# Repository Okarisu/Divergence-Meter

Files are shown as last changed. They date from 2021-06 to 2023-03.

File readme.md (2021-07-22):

# Divergence meter

## from Steins;Gate series and visual novels

## Note - this `readme` is in process of writing, the same as the code

## Basic synopsis

In this project I am trying to build working prototype of Divergence meter that appeared in Steins;Gate anime series and Visual novels.

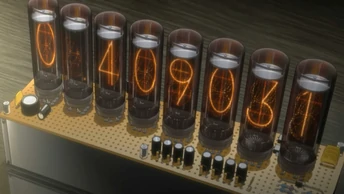
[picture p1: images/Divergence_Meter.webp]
Divergence meter


I use arduino board in combination with shift registers SN74HC595N to drive itrons IV-6.

## byte values for shift registers

### Grids

| Itron No. | byte value |
| --- | --- |
| first |  B01111111 |
| second | B10111111 |
| third | B11011111 |
| fourth | B11101111 |
| fifth | B11110111 |
| sixth | B11111011 |
| seventh | B11111101 |
| eighth | B11111110 |

### Numbers & symbols

| Number | byte value |
| --- | --- |
| zero | B00000011 |
| one | B10011111 |
| two | B00100101 |
| three | B00001101 |
| four | B10110001 |
| five | B01001001 |
| six | B01000001 |
| seven | B00011111 |
| eight | B00000001 |
| nine | B00001001 |

| symbol | byte value |
| --- | --- |
| dot | B11111110 |
| stroke | B11111101 |

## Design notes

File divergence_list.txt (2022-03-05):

-.275349ω
-.195284ω

0.295582α
0.328403α
0.334581α
0.337161α
0.337187α
0.337199α
0.337337α
0.409420α
0.409431α
0.456903α
0.456914α 
0.456923α
0.509736a
0.523299α
0.523307α
0.549111α
0.571015α
0.571024α
0.571046α

SG0
0.571???α
0.571082α

SG
1.048596 (the Steins Gate)
1.048599
1.048728
1.049326X

1.053649β
1.055821β
1.064750β
1.097302β
1.097302β
1.123581β
1.129848β
1.129954β
1.130205β
1.130206β, 1.130207β, 1.130208β, 1.130209β, 1.130211β, 1.130212β
1.130238β
1.130426β
1.143688β
1.382733β

2.615074γ

3.019430δ 
3.030493δ
3.130238δ
3.182879δ
3.372329δ
3.386019δ
3.406288δ
3.600104δ
3.667293δ
3.372329δ, 3.386019δ, 3.406288δ, 3.600104δ, 3.667293δ

4.456441ε, 4.456442ε, 4.493623ε, 4.493624ε, 4.530805ε, 4.530806ε

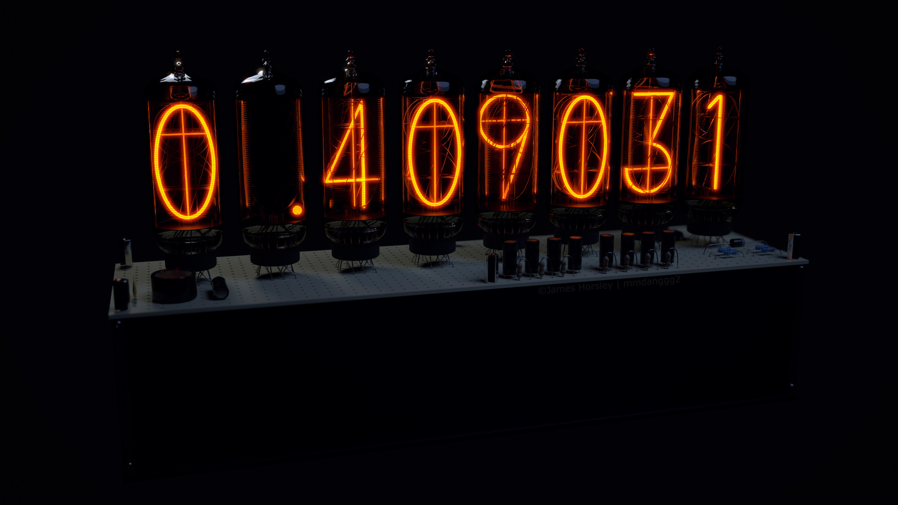
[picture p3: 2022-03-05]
images/james-horsley-nixieview3wm.jpg

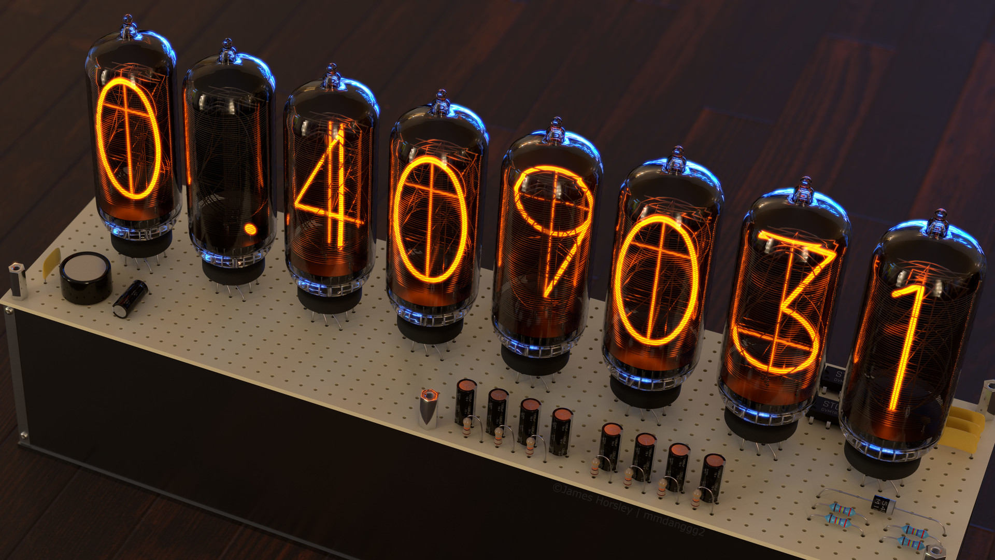
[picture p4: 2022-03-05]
images/james-horsley-nixie8kwm.jpg

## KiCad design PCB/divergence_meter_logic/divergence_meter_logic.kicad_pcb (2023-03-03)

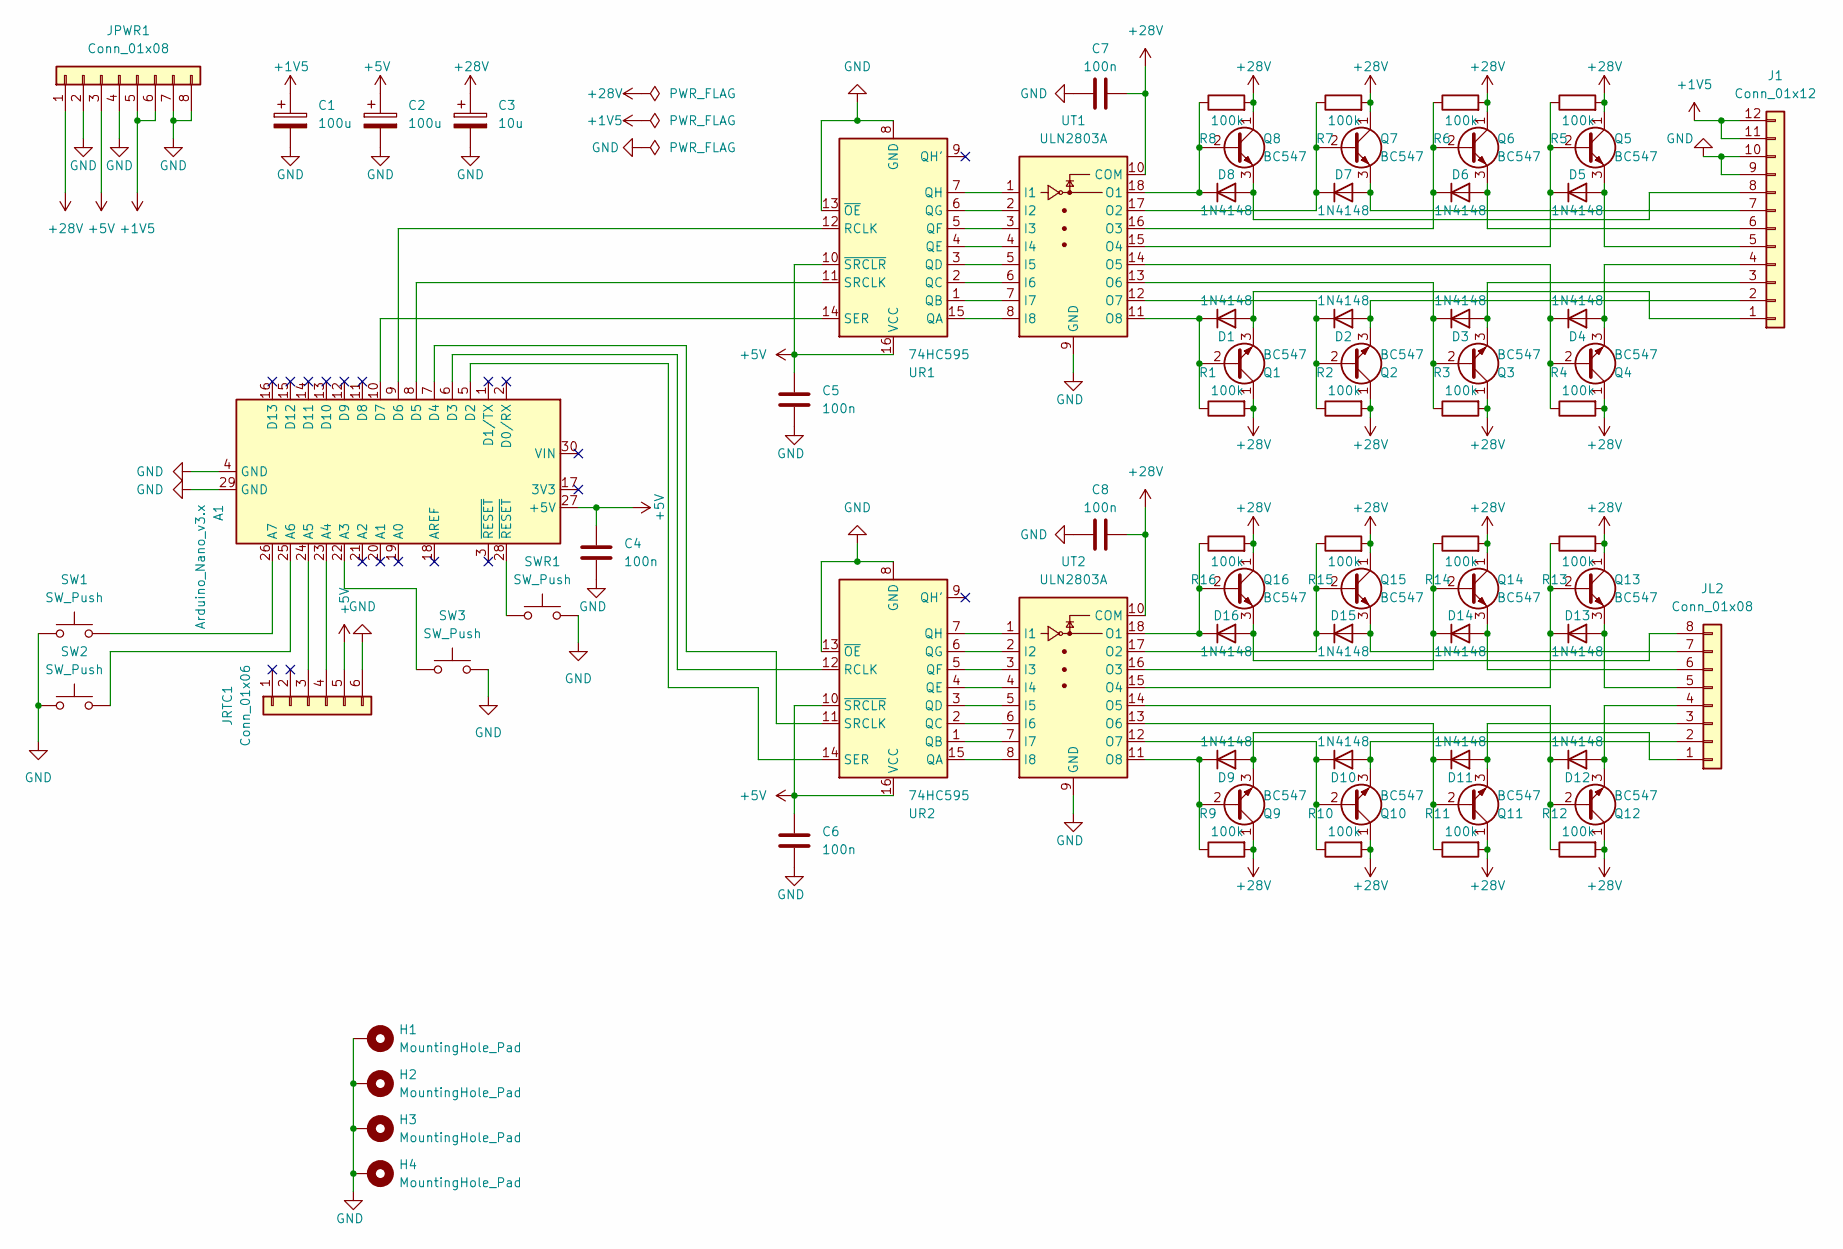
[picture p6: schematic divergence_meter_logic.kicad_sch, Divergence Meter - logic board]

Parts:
A1: Arduino_Nano_v3.x; Arduino_Nano
C1, C2: 100u; CP_Radial_D5.0mm_P2.00mm
C3: 10u; CP_Radial_D5.0mm_P2.00mm
C4, C5, C6, C7, C8: 100n; C_Disc_D5.0mm_W2.5mm_P5.00mm
D1, D2, D3, D4, D5, D6, D7, D8, D9, D10, D11, D12, D13, D14, D15, D16: 1N4148; D_DO-35_SOD27_P2.54mm_Vertical_KathodeUp
H1, H2, H3, H4: MountingHole_Pad; MountingHole_3.5mm_Pad_Via
J1: Conn_01x12; PinSocket_1x12_P2.54mm_Vertical
JL2: Conn_01x08; PinSocket_1x08_P2.54mm_Vertical
JPWR1: Conn_01x08; PinHeader_1x08_P2.54mm_Horizontal
JRTC1: Conn_01x06; PinSocket_1x06_P2.54mm_Horizontal
Q1, Q2, Q3, Q4, Q5, Q6, Q7, Q8, Q9, Q10, Q11, Q12, Q13, Q14, Q15, Q16: BC547; TO-92_Inline
R1, R2, R3, R4, R5, R6, R7, R8, R9, R10, R11, R12, R13, R14, R15, R16: 100k; R_Axial_DIN0204_L3.6mm_D1.6mm_P2.54mm_Vertical
SW1, SW2, SW3: SW_Push; SW_PUSH_6mm_H4.3mm
SWR1: SW_Push; SW_PUSH_6mm_H4.3mm
UR1, UR2: 74HC595; DIP-16_W7.62mm_Socket
UT1, UT2: ULN2803A; DIP-18_W7.62mm_Socket

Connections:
+1V5: C1.1, J1.11, J1.12, JPWR1.5, JPWR1.6
+5V: A1.27 (+5V), C2.1, C4.1, C5.1, C6.1, JPWR1.3, JRTC1.5, UR1.10 (~SRCLR), UR1.16 (VCC), UR2.10 (~SRCLR), UR2.16 (VCC)
+28V: C3.1, C7.2, C8.2, JPWR1.1, Q1.1 (C), Q2.1 (C), Q3.1 (C), Q4.1 (C), Q5.1 (C), Q6.1 (C), Q7.1 (C), Q8.1 (C), Q9.1 (C), Q10.1 (C), Q11.1 (C), Q12.1 (C), Q13.1 (C), Q14.1 (C), Q15.1 (C), Q16.1 (C), R1.2, R2.2, R3.2, R4.2, R5.2, R6.2, R7.2, R8.2, R9.2, R10.2, R11.2, R12.2, R13.2, R14.2, R15.2, R16.2, UT1.10 (COM), UT2.10 (COM)
GND: A1.4 (GND), A1.29 (GND), C1.2, C2.2, C3.2, C4.2, C5.2, C6.2, C7.1, C8.1, H1.1, H2.1, H3.1, H4.1, J1.9, J1.10, JPWR1.2, JPWR1.4, JPWR1.7, JPWR1.8, JRTC1.6, SW1.1, SW2.1, SW3.2, SWR1.2, UR1.8 (GND), UR1.13 (~OE), UR2.8 (GND), UR2.13 (~OE), UT1.9 (GND), UT2.9 (GND)
unnamed: A1.5 (D2), UR2.14 (SER)
unnamed: A1.6 (D3), UR2.12 (RCLK)
unnamed: A1.7 (D4), UR2.11 (SRCLK)
unnamed: A1.22 (A3), SW3.1
unnamed: A1.23 (A4), JRTC1.4
unnamed: A1.24 (A5), JRTC1.3
unnamed: A1.25 (A6), SW2.2
unnamed: A1.26 (A7), SW1.2
unnamed: A1.28 (~RESET), SWR1.1
unnamed: D1.1 (K), Q1.2 (B), R1.1, UT1.11 (O8)
unnamed: D1.2 (A), J1.1, Q1.3 (E)
unnamed: D2.1 (K), Q2.2 (B), R2.1, UT1.12 (O7)
unnamed: D2.2 (A), J1.2, Q2.3 (E)
unnamed: D3.1 (K), Q3.2 (B), R3.1, UT1.13 (O6)
unnamed: D3.2 (A), J1.3, Q3.3 (E)
unnamed: D4.1 (K), Q4.2 (B), R4.1, UT1.14 (O5)
unnamed: D4.2 (A), J1.4, Q4.3 (E)
unnamed: D5.1 (K), Q5.2 (B), R5.1, UT1.15 (O4)
unnamed: D5.2 (A), J1.5, Q5.3 (E)
unnamed: D6.1 (K), Q6.2 (B), R6.1, UT1.16 (O3)
unnamed: D6.2 (A), J1.6, Q6.3 (E)
unnamed: D7.1 (K), Q7.2 (B), R7.1, UT1.17 (O2)
unnamed: D7.2 (A), J1.7, Q7.3 (E)
unnamed: D8.1 (K), Q8.2 (B), R8.1, UT1.18 (O1)
unnamed: D8.2 (A), J1.8, Q8.3 (E)
unnamed: D9.1 (K), Q9.2 (B), R9.1, UT2.11 (O8)
unnamed: D9.2 (A), JL2.1, Q9.3 (E)
unnamed: D10.1 (K), Q10.2 (B), R10.1, UT2.12 (O7)
unnamed: D10.2 (A), JL2.2, Q10.3 (E)
unnamed: D11.1 (K), Q11.2 (B), R11.1, UT2.13 (O6)
unnamed: D11.2 (A), JL2.3, Q11.3 (E)
unnamed: D12.1 (K), Q12.2 (B), R12.1, UT2.14 (O5)
unnamed: D12.2 (A), JL2.4, Q12.3 (E)
unnamed: D13.1 (K), Q13.2 (B), R13.1, UT2.15 (O4)
unnamed: D13.2 (A), JL2.5, Q13.3 (E)
unnamed: D14.1 (K), Q14.2 (B), R14.1, UT2.16 (O3)
unnamed: D14.2 (A), JL2.6, Q14.3 (E)
unnamed: D15.1 (K), Q15.2 (B), R15.1, UT2.17 (O2)
unnamed: D15.2 (A), JL2.7, Q15.3 (E)
unnamed: D16.1 (K), Q16.2 (B), R16.1, UT2.18 (O1)
unnamed: D16.2 (A), JL2.8, Q16.3 (E)
unnamed: UR1.1 (QB), UT1.7 (I7)
unnamed: UR1.2 (QC), UT1.6 (I6)
unnamed: UR1.3 (QD), UT1.5 (I5)
unnamed: UR1.4 (QE), UT1.4 (I4)
unnamed: UR1.5 (QF), UT1.3 (I3)
unnamed: UR1.6 (QG), UT1.2 (I2)
unnamed: UR1.7 (QH), UT1.1 (I1)
unnamed: A1.8 (D5), UR1.11 (SRCLK)
unnamed: A1.9 (D6), UR1.12 (RCLK)
unnamed: A1.10 (D7), UR1.14 (SER)
unnamed: UR1.15 (QA), UT1.8 (I8)
unnamed: UR2.1 (QB), UT2.7 (I7)
unnamed: UR2.2 (QC), UT2.6 (I6)
unnamed: UR2.3 (QD), UT2.5 (I5)
unnamed: UR2.4 (QE), UT2.4 (I4)
unnamed: UR2.5 (QF), UT2.3 (I3)
unnamed: UR2.6 (QG), UT2.2 (I2)
unnamed: UR2.7 (QH), UT2.1 (I1)
unnamed: UR2.15 (QA), UT2.8 (I8)

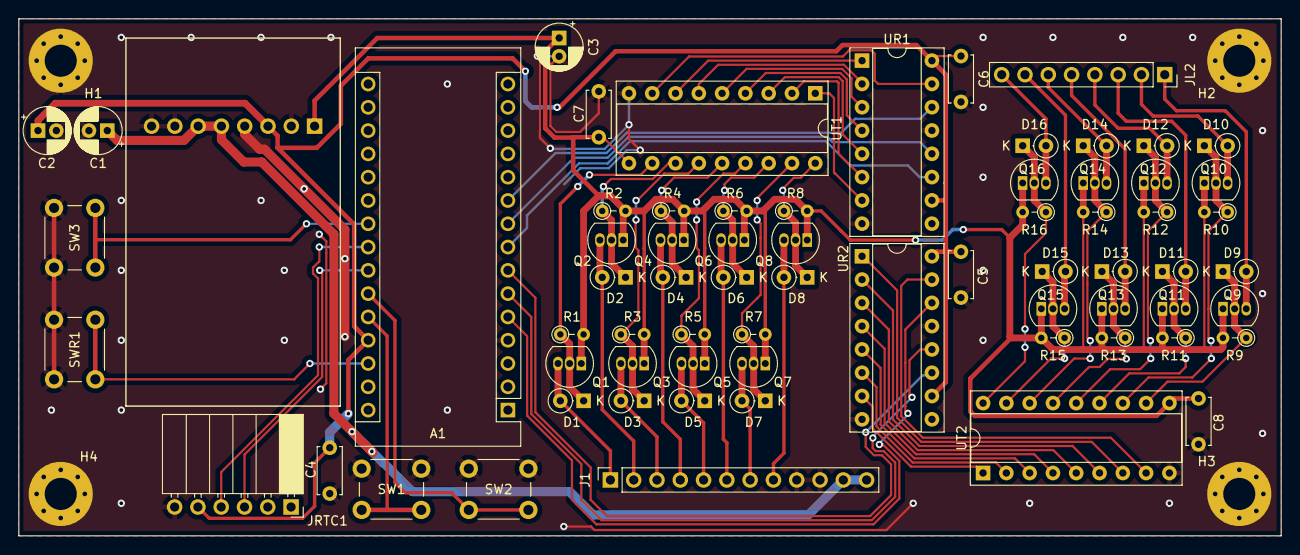
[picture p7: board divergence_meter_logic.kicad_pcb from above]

Board: 2 copper layers, 137.7 x 56.4 mm, 73 parts (1 on the bottom side), 64 nets.

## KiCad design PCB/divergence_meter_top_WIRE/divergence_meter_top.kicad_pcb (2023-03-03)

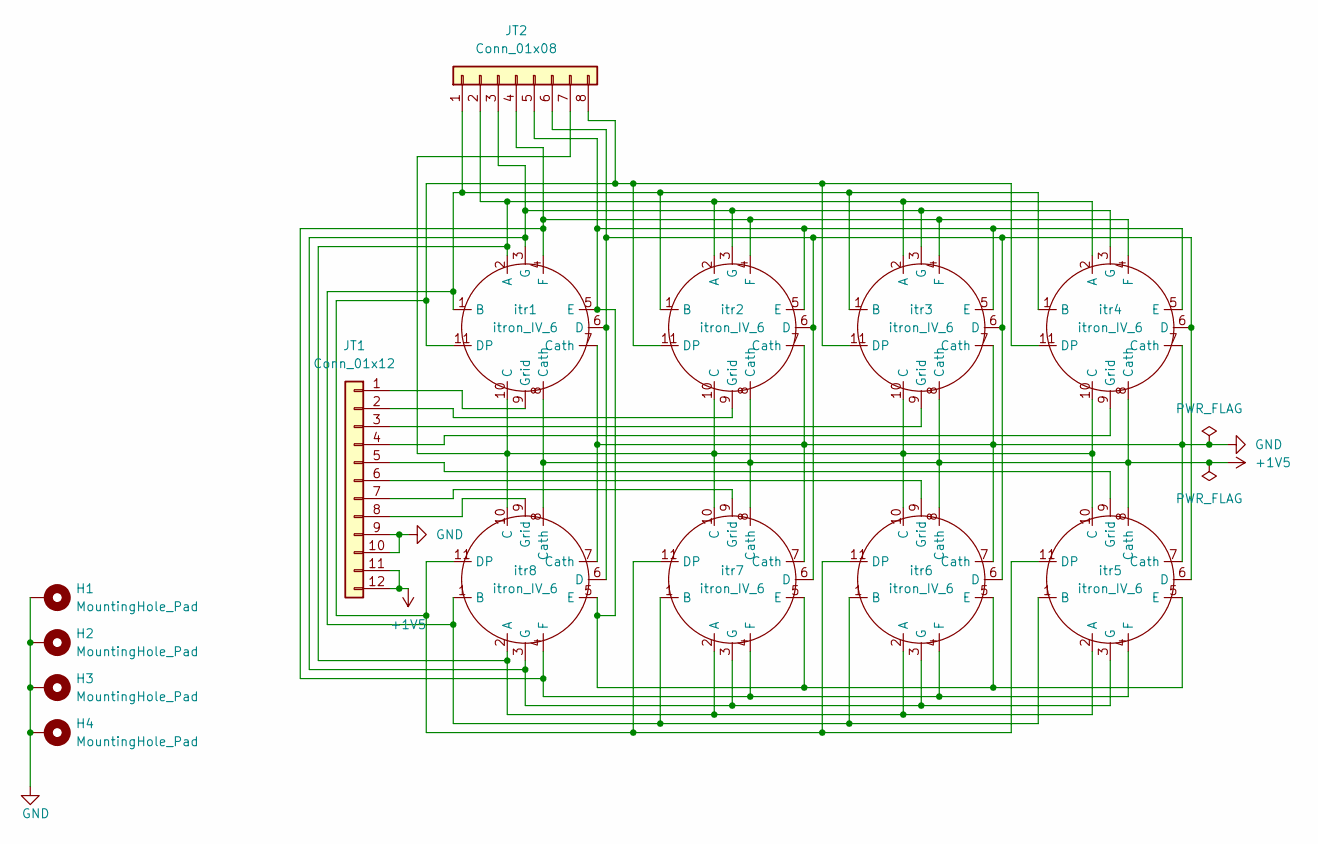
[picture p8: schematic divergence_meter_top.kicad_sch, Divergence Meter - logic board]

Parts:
H1, H2, H3, H4: MountingHole_Pad; MountingHole_3.5mm_Pad_Via
JT1: Conn_01x12; PinHeader_1x12_P2.54mm_Vertical
JT2: Conn_01x08; PinHeader_1x08_P2.54mm_Vertical
itr1, itr2, itr3, itr4, itr5, itr6, itr7, itr8: itron_IV_6

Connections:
+1V5: JT1.11, JT1.12, itr1.8 (Cath), itr2.8 (Cath), itr3.8 (Cath), itr4.8 (Cath), itr5.8 (Cath), itr6.8 (Cath), itr7.8 (Cath), itr8.8 (Cath)
GND: H1.1, H2.1, H3.1, H4.1, JT1.9, JT1.10, itr1.7 (Cath), itr2.7 (Cath), itr3.7 (Cath), itr4.7 (Cath), itr5.7 (Cath), itr6.7 (Cath), itr7.7 (Cath), itr8.7 (Cath)
unnamed: JT1.1, itr1.9 (Grid)
unnamed: JT1.2, itr2.9 (Grid)
unnamed: JT1.3, itr3.9 (Grid)
unnamed: JT1.4, itr4.9 (Grid)
unnamed: JT1.5, itr5.9 (Grid)
unnamed: JT1.6, itr6.9 (Grid)
unnamed: JT1.7, itr7.9 (Grid)
unnamed: JT1.8, itr8.9 (Grid)
unnamed: JT2.1, itr1.1 (B), itr2.1 (B), itr3.1 (B), itr4.1 (B), itr5.1 (B), itr6.1 (B), itr7.1 (B), itr8.1 (B)
unnamed: JT2.2, itr1.2 (A), itr2.2 (A), itr3.2 (A), itr4.2 (A), itr5.2 (A), itr6.2 (A), itr7.2 (A), itr8.2 (A)
unnamed: JT2.3, itr1.3 (G), itr2.3 (G), itr3.3 (G), itr4.3 (G), itr5.3 (G), itr6.3 (G), itr7.3 (G), itr8.3 (G)
unnamed: JT2.4, itr1.4 (F), itr2.4 (F), itr3.4 (F), itr4.4 (F), itr5.4 (F), itr6.4 (F), itr7.4 (F), itr8.4 (F)
unnamed: JT2.5, itr1.5 (E), itr2.5 (E), itr3.5 (E), itr4.5 (E), itr5.5 (E), itr6.5 (E), itr7.5 (E), itr8.5 (E)
unnamed: JT2.6, itr1.6 (D), itr2.6 (D), itr3.6 (D), itr4.6 (D), itr5.6 (D), itr6.6 (D), itr7.6 (D), itr8.6 (D)
unnamed: JT2.7, itr1.10 (C), itr2.10 (C), itr3.10 (C), itr4.10 (C), itr5.10 (C), itr6.10 (C), itr7.10 (C), itr8.10 (C)
unnamed: JT2.8, itr1.11 (DP), itr2.11 (DP), itr3.11 (DP), itr4.11 (DP), itr5.11 (DP), itr6.11 (DP), itr7.11 (DP), itr8.11 (DP)

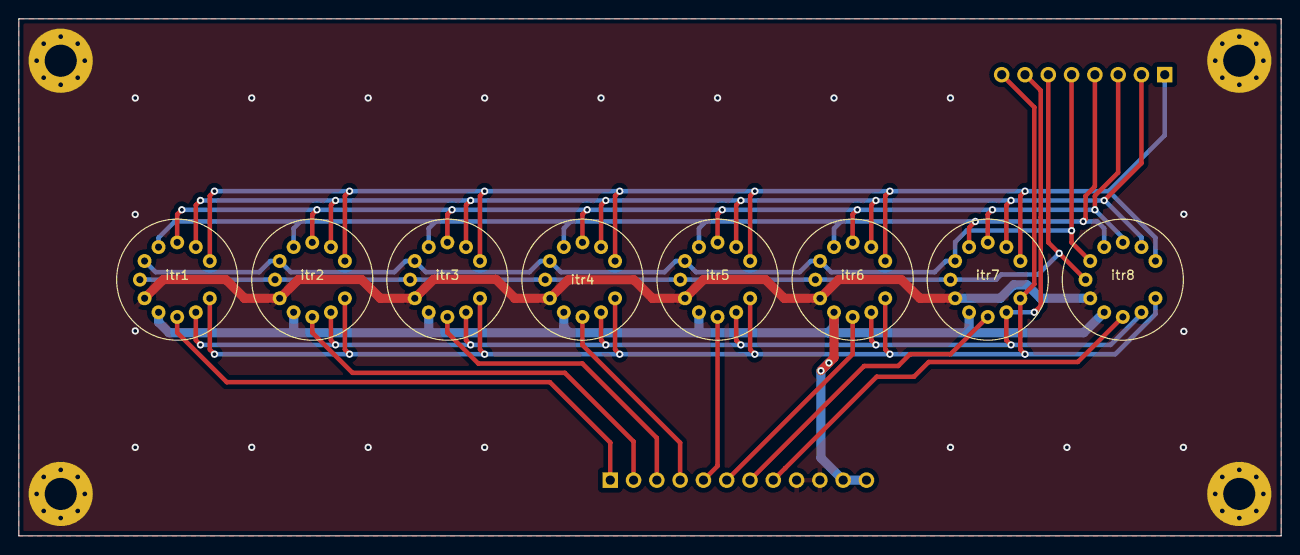
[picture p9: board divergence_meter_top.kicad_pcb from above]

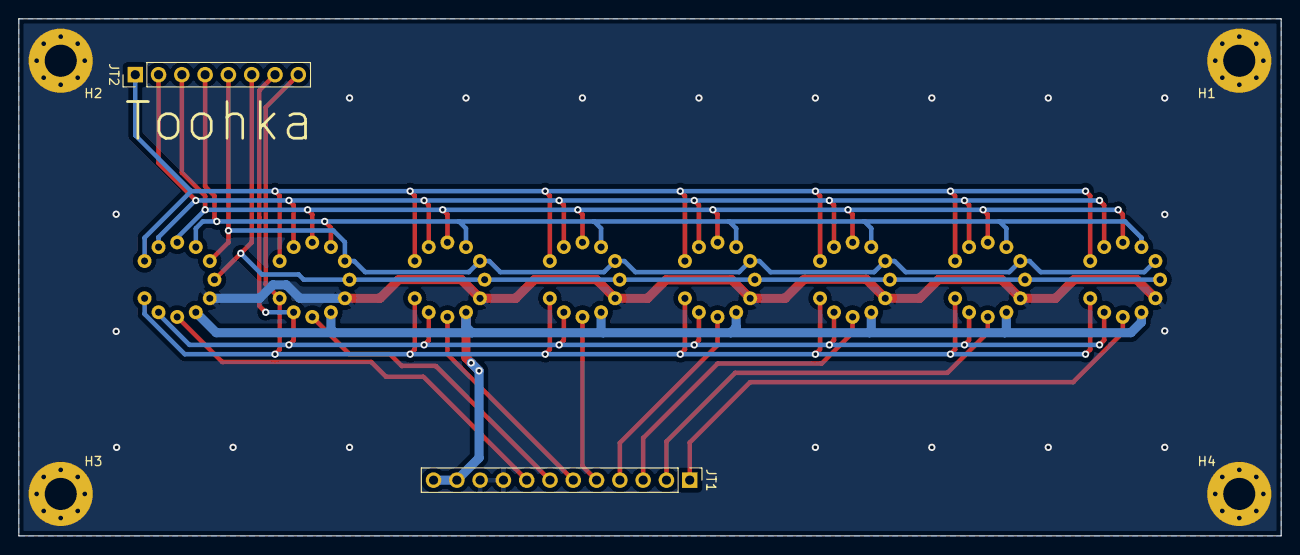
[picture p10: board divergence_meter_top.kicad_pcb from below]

Board: 2 copper layers, 137.7 x 56.4 mm, 14 parts (2 on the bottom side), 18 nets.

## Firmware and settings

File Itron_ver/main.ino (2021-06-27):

//libraries init
#include <Wire.h>
#include <DS3231.h>

//RTC module variables
DS3231 rtc;
RTCDateTime dateTime;

//RTC module pinnout
int SCLpin = A5;
int SDApin = A4;


bool power = false;

bool divergence = false; //When true, divergence value is displayed. When false, current time is displayed.

//segment shift register pinnout
int registerSegmentLatchPin;
int registerSegmentClockPin;
int registerSegmentDataPin;

//grids shift register pinnout
int registerGridLatchPin;
int registerGridClockPin;
int registerGridDataPin;


//array with bytes to write through registers
byte divergenceArray[8]; //array with elements to display numbers
byte divergenceGridArray[8]; //array with elements to power on itron grids
int divergenceArrayPosition = 0; //variable for array element selection

delayNumberChangeTime

void setup()
{
    pinMode(registerSegmentLatchPin, OUTPUT);
    pinMode(registerSegmentClockPin, OUTPUT);
    pinMode(registerSegmentDataPin, OUTPUT);

    pinMode(registerGridLatchPin, OUTPUT);
    pinMode(registerGridClockPin, OUTPUT);
    pinMode(registerGridDataPin, OUTPUT);

}

void display()
{
    for(divergenceArrayPosition; divergenceArrayPosition < 8; divergenceArrayPosition++){

        digitalWrite(registerSegmentLatchPin, LOW);
        digitalWrite(registerGridLatchPin, LOW);

        shiftOut(registerSegmentDataPin, registerSegmentClockPin, LSBFIRST, divergenceArray[divergenceArrayPosition]);
        shiftOut(registerGridDataPin, registerGridClockPin, LSBFIRST, divergenceGridArray[divergenceArrayPosition]);

        digitalWrite(registerSegmentLatchPin, HIGH);
        digitalWrite(registerGridLatchPin, HIGH);

        delay(delayNumberChangeTime)
}

void divergence(){
divergenceArray[divergenceArrayPosition] = B01111111;

}

void getTime(){

    dateTime = rtc.getDateTime();

    //GET HOUR
    if(dateTime.hour <= 9){

        divergenceArray[0] = displayZero; //display 0 on the first itron

        switch(dateTime.hour) {

            case 0:
                divergenceArray[2] = displayZero;
                break;

            case 1:
                divergenceArray[2] = displayOne;
                break;
            
            case 2:
                divergenceArray[2] = displayTwo;
                break;
            
            case 3:
                divergenceArray[2] = displayThree;
                break;

            case 4:
                divergenceArray[2] = displayFour;
                break;
            
            case 5:
                divergenceArray[2] = displayFive;
                break;
            
            case 6:
                divergenceArray[2] = displaySix;
                break;
            
            case 7:
                divergenceArray[2] = displaySeven;
                break;

            case 8:
                divergenceArray[2] = displayEight;
                break;
            
            case 9:
                divergenceArray[2] = displayNine;
                break;
        }
    } else if ((dateTime.hour >= 10) && (dateTime.hour <= 19)){

        divergenceArray[0] = displayOne; //display 1 on the first itron

        switch(dateTime.hour){


            case 10:
                divergenceArray[2] = displayZero;
                break;

            case 11:
                divergenceArray[2] = displayOne;
                break;

            case 12:
                divergenceArray[2] = displayTwo;
                break;

            case 13:
                divergenceArray[2] = displayThree;
                break;

            case 14:
                divergenceArray[2] = displayFour;
                break;

            case 15:
                divergenceArray[2] = displayFive;
                break;

            case 16:
                divergenceArray[2] = displaySix;
                break;

            case 17:
                divergenceArray[2] = displaySeven;
                break;

            case 18:
                divergenceArray[2] = displayEight;
                break;

            case 19:
                divergenceArray[2] = displayNine;
                break;
        }

    } else if ((dateTime.hour >= 20) && (dateTime.hour < 24)){

        divergenceArray[0] = displayTwo; //display 2 on the first itron

        switch(dateTime.hour){

            case 20:
                divergenceArray[2] = displayZero;
                break;

            case 21:
                divergenceArray[2] = displayOne;
                break;

            case 22:
                divergenceArray[2] = displayTwo;
                break;

            case 23:
                divergenceArray[2] = displayThree;
                break;
        }

    }
    //!GET HOUR

    divergenceArray[4] = B11111101; //display '-' on the third itron


    //GET MINUTE
    if(dateTime.minute <= 9){

        divergenceArray[6] = displayZero; //display 0 on the fourth itron

        switch(dateTime.minute) {

            case 0:
                divergenceArray[8] = displayZero;
                break;

            case 1:
                divergenceArray[8] = displayOne;
                break;
            
            case 2:
                divergenceArray[8] = displayTwo;
                break;
            
            case 3:
                divergenceArray[8] = displayThree;
                break;

            case 4:
                divergenceArray[8] = displayFour;
                break;
            
            case 5:
                divergenceArray[8] = displayFive;
                break;
            
            case 6:
                divergenceArray[8] = displaySix;
                break;
            
            case 7:
                divergenceArray[8] = displaySeven;
                break;

            case 8:
                divergenceArray[8] = displayEight;
                break;
            
            case 9:
                divergenceArray[8] = displayNine;
                break;
        }
    
    } else if ((dateTime.minute >= 10) && (dateTime.minute <= 19)){

        divergenceArray[6] = displayOne; //display 1 on the fourth itron

        switch(dateTime.minute){


            case 10:
                divergenceArray[8] = displayZero;
                break;

            case 11:
                divergenceArray[8] = displayOne;
                break;

            case 12:
                divergenceArray[8] = displayTwo;
                break;

            case 13:
                divergenceArray[8] = displayThree;
                break;

            case 14:
                divergenceArray[8] = displayFour;
                break;

            case 15:
                divergenceArray[8] = displayFive;
                break;

            case 16:
                divergenceArray[8] = displaySix;
                break;

            case 17:
                divergenceArray[8] = displaySeven;
                break;

            case 18:
                divergenceArray[8] = displayEight;
                break;

            case 19:
                divergenceArray[8] = displayNine;
                break;
        }
    
    } else if ((dateTime.minute >= 20) && (dateTime.minute <= 29)){

        divergenceArray[6] = displayTwo; //display 2 on the fourth itron

        switch(dateTime.minute){


            case 20:
                divergenceArray[8] = displayZero;
                break;

            case 21:
                divergenceArray[8] = displayOne;
                break;

            case 22:
                divergenceArray[8] = displayTwo;
                break;

            case 23:
                divergenceArray[8] = displayThree;
                break;

            case 24:
                divergenceArray[8] = displayFour;
                break;

            case 25:
                divergenceArray[8] = displayFive;
                break;

            case 26:
                divergenceArray[8] = displaySix;
                break;

            case 27:
                divergenceArray[8] = displaySeven;
                break;

            case 28:
                divergenceArray[8] = displayEight;
                break;

            case 29:
                divergenceArray[8] = displayNine;
                break;
        }
    
    } else if ((dateTime.minute >= 30) && (dateTime.minute <= 39)){

        divergenceArray[6] = displayThree; //display 3 on the fourth itron

        switch(dateTime.minute){


            case 30:
                divergenceArray[8] = displayZero;
                break;

            case 31:
                divergenceArray[8] = displayOne;
                break;

            case 32:
                divergenceArray[8] = displayTwo;
                break;

            case 33:
                divergenceArray[8] = displayThree;
                break;

            case 34:
                divergenceArray[8] = displayFour;
                break;

            case 35:
                divergenceArray[8] = displayFive;
                break;

            case 36:
                divergenceArray[8] = displaySix;
                break;

            case 37:
                divergenceArray[8] = displaySeven;
                break;

            case 38:
                divergenceArray[8] = displayEight;
                break;

            case 39:
                divergenceArray[8] = displayNine;
                break;
        }

    } else if ((dateTime.minute >= 40) && (dateTime.minute <= 49)){

        divergenceArray[6] = displayFour; //display 4 on the fourth itron

        switch(dateTime.minute){


            case 40:
                divergenceArray[8] = displayZero;
                break;

            case 41:
                divergenceArray[8] = displayOne;
                break;

            case 42:
                divergenceArray[8] = displayTwo;
                break;

            case 43:
                divergenceArray[8] = displayThree;
                break;

            case 44:
                divergenceArray[8] = displayFour;
                break;

            case 45:
                divergenceArray[8] = displayFive;
                break;

            case 46:
                divergenceArray[8] = displaySix;
                break;

            case 47:
                divergenceArray[8] = displaySeven;
                break;

            case 48:
                divergenceArray[8] = displayEight;
                break;

            case 49:
                divergenceArray[8] = displayNine;
                break;
        }

    } else if ((dateTime.minute >= 50) && (dateTime.minute <= 59)){

        divergenceArray[6] = displayFive; //display 5 on the fourth itron

        switch(dateTime.minute){


            case 50:
                divergenceArray[8] = displayZero;
                break;

            case 51:
                divergenceArray[8] = displayOne;
                break;

            case 52:
                divergenceArray[8] = displayTwo;
                break;

            case 53:
                divergenceArray[8] = displayThree;
                break;

            case 54:
                divergenceArray[8] = displayFour;
                break;

            case 55:
                divergenceArray[8] = displayFive;
                break;

            case 56:
                divergenceArray[8] = displaySix;
                break;

            case 57:
                divergenceArray[8] = displaySeven;
                break;

            case 58:
                divergenceArray[8] = displayEight;
                break;

            case 59:
                divergenceArray[8] = displayNine;
                break;
        }
    }
    //!GET MINUTE

    divergenceArray[10] = B11111101; //display '-' on the sixth itron


    //GET SECOND
    if(dateTime.second <= 9){

        divergenceArray[12] = displayZero; //display 0 on the seventh itron

        switch(dateTime.second) {

            case 0:
                divergenceArray[14] = displayZero;
                break;

            case 1:
                divergenceArray[14] = displayOne;
                break;
            
            case 2:
                divergenceArray[14] = displayTwo;
                break;
            
            case 3:
                divergenceArray[14] = displayThree;
                break;

            case 4:
                divergenceArray[14] = displayFour;
                break;
            
            case 5:
                divergenceArray[14] = displayFive;
                break;
            
            case 6:
                divergenceArray[14] = displaySix;
                break;
            
            case 7:
                divergenceArray[14] = displaySeven;
                break;

            case 8:
                divergenceArray[14] = displayEight;
                break;
            
            case 9:
                divergenceArray[14] = displayNine;
                break;
        }
    
    } else if ((dateTime.second >= 10) && (dateTime.second <= 19)){

        divergenceArray[6] = displayOne; //display 1 on the seventh itron

        switch(dateTime.second){


            case 10:
                divergenceArray[14] = displayZero;
                break;

            case 11:
                divergenceArray[14] = displayOne;
                break;

            case 12:
                divergenceArray[14] = displayTwo;
                break;

            case 13:
                divergenceArray[14] = displayThree;
                break;

            case 14:
                divergenceArray[14] = displayFour;
                break;

            case 15:
                divergenceArray[14] = displayFive;
                break;

            case 16:
                divergenceArray[14] = displaySix;
                break;

            case 17:
                divergenceArray[14] = displaySeven;
                break;

            case 18:
                divergenceArray[14] = displayEight;
                break;

            case 19:
                divergenceArray[14] = displayNine;
                break;
        }
    
    } else if ((dateTime.second >= 20) && (dateTime.second <= 29)){

        divergenceArray[6] = displayTwo; //display 2 on the seventh itron

        switch(dateTime.second){


            case 20:
                divergenceArray[14] = displayZero;
                break;

            case 21:
                divergenceArray[14] = displayOne;
                break;

            case 22:
                divergenceArray[14] = displayTwo;
                break;

            case 23:
                divergenceArray[14] = displayThree;
                break;

            case 24:
                divergenceArray[14] = displayFour;
                break;

            case 25:
                divergenceArray[14] = displayFive;
                break;

            case 26:
                divergenceArray[14] = displaySix;
                break;

            case 27:
                divergenceArray[14] = displaySeven;
                break;

            case 28:
                divergenceArray[14] = displayEight;
                break;

            case 29:
                divergenceArray[14] = displayNine;
                break;
        }
    
    } else if ((dateTime.second >= 30) && (dateTime.second <= 39)){

        divergenceArray[6] = displayThree; //display 3 on the seventh itron

        switch(dateTime.second){


            case 30:
                divergenceArray[14] = displayZero;
                break;

            case 31:
                divergenceArray[14] = displayOne;
                break;

            case 32:
                divergenceArray[14] = displayTwo;
                break;

            case 33:
                divergenceArray[14] = displayThree;
                break;

            case 34:
                divergenceArray[14] = displayFour;
                break;

            case 35:
                divergenceArray[14] = displayFive;
                break;

            case 36:
                divergenceArray[14] = displaySix;
                break;

            case 37:
                divergenceArray[14] = displaySeven;
                break;

            case 38:
                divergenceArray[14] = displayEight;
                break;

            case 39:
                divergenceArray[14] = displayNine;
                break;
        }

    } else if ((dateTime.second >= 40) && (dateTime.second <= 49)){

        divergenceArray[6] = displayFour; //display 4 on the seventh itron

        switch(dateTime.second){


            case 40:
                divergenceArray[14] = displayZero;
                break;

            case 41:
                divergenceArray[14] = displayOne;
                break;

            case 42:
                divergenceArray[14] = displayTwo;
                break;

            case 43:
                divergenceArray[14] = displayThree;
                break;

            case 44:
                divergenceArray[14] = displayFour;
                break;

            case 45:
                divergenceArray[14] = displayFive;
                break;

            case 46:
                divergenceArray[14] = displaySix;
                break;

            case 47:
                divergenceArray[14] = displaySeven;
                break;

            case 48:
                divergenceArray[14] = displayEight;
                break;

            case 49:
                divergenceArray[14] = displayNine;
                break;
        }

    } else if ((dateTime.second >= 50) && (dateTime.second <= 59)){

        divergenceArray[6] = displayFive; //display 5 on the seventh itron

        switch(dateTime.second){


            case 50:
                divergenceArray[14] = displayZero;
                break;

            case 51:
                divergenceArray[14] = displayOne;
                break;

            case 52:
                divergenceArray[14] = displayTwo;
                break;

            case 53:
                divergenceArray[14] = displayThree;
                break;

            case 54:
                divergenceArray[14] = displayFour;
                break;

            case 55:
                divergenceArray[14] = displayFive;
                break;

            case 56:
                divergenceArray[14] = displaySix;
                break;

            case 57:
                divergenceArray[14] = displaySeven;
                break;

            case 58:
                divergenceArray[14] = displayEight;
                break;

            case 59:
                divergenceArray[14] = displayNine;
                break;
        }
    }
    //!GET SECOND

}

byte displayZero = B00000011;
byte displayOne = B10011111;
byte displayTwo = B00100101;
byte displayThree = B00001101;
byte displayFour = B10110001;
byte displayFive = B01001001;
byte displaySix = B01000001;
byte displaySeven = B00011111;
byte displayEight = B00000001;
byte displayNine = B00001001;
byte displayDot = B11111110;

byte onFirst = B01111111;
byte onSecond = B10111111;
byte onThird = B11011111;
byte onFourth = B11101111;
byte onFifth = B11110111;
byte onSixth = B11111011;
byte onSeventh = B11111101;
byte onEight = B11111110;

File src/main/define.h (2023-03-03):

//
// Created by Toohka on 01.06.2022.
//

#ifndef SRC_PINOUT_H
#define SRC_PINOUT_H

//pinout
#define segmentLatchPin 1
#define segmentDataPin 2
#define segmentClockPin 3

#define gridLatchPin 4
#define gridDataPin 5
#define gridClockPin 6

#define modeSwitch 7
#define scrambleSwitch 8
#define setSwitch 9

//hodnoty
#define displayCycleDelay 10
#define pushLimit 25
#define scrambleLength 5000

#endif //SRC_PINOUT_H

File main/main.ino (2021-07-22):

//libraries init
#include <Wire.h>
#include <DS3231.h>

//RTC module pinnout
int SCLpin = A5;
int SDApin = A4;

bool power = true; //Switch variable - when false, nothing is being displayed

bool divergence = false; //When true, divergence value is displayed. When false, current time is displayed.

//segments shift register pinnout
int registerSegmentLatchPin;
int registerSegmentClockPin;
int registerSegmentDataPin;

//grids shift register pinnout
int registerGridLatchPin;
int registerGridClockPin;
int registerGridDataPin;

/*arrays with bytes to write through registers*/

byte divergenceArray[8]; //array with elements to display numbers

//array with elements to power itron grids; each array element represents one itron powered on
byte divergenceGridArray[] = {B01111111, B10111111, B11011111, B11101111, B11110111, B11111011, B11111101, B11111110};

int divergenceArrayPosition = 0; //variable for array element selection

int delayNumberChangeTime = 10; //delay in ms to switch between powering itrons

void setup()
{

    /*setting all driving pins to OUTPUT from Arduino board*/
    pinMode(registerSegmentLatchPin, OUTPUT);
    pinMode(registerSegmentClockPin, OUTPUT);
    pinMode(registerSegmentDataPin, OUTPUT);

    pinMode(registerGridLatchPin, OUTPUT);
    pinMode(registerGridClockPin, OUTPUT);
    pinMode(registerGridDataPin, OUTPUT);
}

void loop(){
    if(divergence){
        divergence();
    } else if (!divergence){
        getTime();
    }

    display();
}

void display()
{

    //cycle to go through all digits and display them 
    for (divergenceArrayPosition; divergenceArrayPosition < 8; divergenceArrayPosition++)
    {

        //seting latch pins of both shift registers to LOW to be able to write data to them
        digitalWrite(registerSegmentLatchPin, LOW);
        digitalWrite(registerGridLatchPin, LOW);

        //writing data to the shift registers
        shiftOut(registerSegmentDataPin, registerSegmentClockPin, LSBFIRST, divergenceArray[divergenceArrayPosition]); //write digit to be displayed to the shift register driving itron segments

        shiftOut(registerGridDataPin, registerGridClockPin, LSBFIRST, divergenceGridArray[divergenceArrayPosition]); //turning on the itron

        //seting latch pins of both shift registers to HIGH to display the digit
        digitalWrite(registerSegmentLatchPin, HIGH);
        digitalWrite(registerGridLatchPin, HIGH);

        //delay to get whole displaying process on certain frequency
        delay(delayNumberChangeTime);
    }
}

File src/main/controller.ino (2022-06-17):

#include <Arduino.h>
#include "byte_lib.h"
#include "matrix.h"
#include "fetch_time.ino"
#include "display.ino"

void Controller (bool divergence) {
    if (divergence) {
        byte divergenceArray[8] = {
                matrix[random(0, 10)],
                symDot,
                matrix[random(0, 10)],
                matrix[random(0, 10)],
                matrix[random(0, 10)],
                matrix[random(0, 10)],
                matrix[random(0, 10)],
                matrix[random(0, 10)]
        };
        Display(divergenceArray);

    } else {

        byte timeArray[8] = {
                matrix[FetchTime(1)],
                matrix[FetchTime(2)],
                symStroke,
                matrix[FetchTime(3)],
                matrix[FetchTime(4)],
                symStroke,
                matrix[FetchTime(5)],
                matrix[FetchTime(6)],
        };

        Display(timeArray);

    }

}

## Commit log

2021-06-13 change deployment from LED to Itron version
2021-07-30 split lang versions, corrected display position
    [display.ino, divergence.ino, getTime.ino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]
2022-01-07 všehocommit
    [divergence_meter.kicad_pcb, divergence_meter.sch]
2022-03-05 Finished schematics, started PCB design
    Some schematics changes may be added
    [divergence_meter.kicad_pcb, divergence_meter.kicad_sch, divergence_meter.sch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]
2022-03-06 working on PCB - itron board almost done
    [divergence_meter.kicad_pcb, divergence_meter.kicad_sch, top_board.kicad_sch]
2022-03-09 itrons done, started logics
    [divergence_meter.kicad_pcb, divergence_meter.kicad_sch]
2022-05-11 skoro hotova horní deska
    [divergence_meter.kicad_pcb, divergence_meter.kicad_sch]
2022-05-27 fakt nevim
    [divergence_meter.kicad_pcb, divergence_meter.kicad_sch]
2022-05-27 Dokončena horní deska
    [divergence_meter.kicad_pcb, divergence_meter.kicad_sch]
2022-05-27 kicad refactor
    [divergence_meter.kicad_pcb, divergence_meter.kicad_sch, divergence_meter_logic.kicad_pcb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]
2022-05-27 remake pcb
    [divergence_meter_logic.kicad_pcb, divergence_meter_logic.kicad_sch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]
2022-06-01 code rework - display & time
    [divergence_meter_logic.kicad_sch]
2022-06-19 pcb rework
    [divergence_meter_logic.kicad_pcb, divergence_meter_logic.kicad_sch]
2022-06-19 pcb finishing
    [divergence_meter_logic.kicad_pcb, divergence_meter_logic.kicad_sch]
2022-06-23 logic pcb almost finished, remaking top
    [divergence_meter_logic.kicad_pcb, divergence_meter_logic.kicad_sch, divergence_meter_top.kicad_pcb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]
2022-06-23 top done, logic almost
    [divergence_meter_logic.kicad_pcb, divergence_meter_logic.kicad_sch, divergence_meter_top.kicad_pcb]
2022-06-24 PCB done, exported gerber
    [divergence_meter_logic-B_Cu.gbl, divergence_meter_logic-B_Mask.gbs, divergence_meter_logic-B_Paste.gbp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]
2023-02-17 reviewed logic board
    [divergence_meter_logic.kicad_pcb, divergence_meter_logic.kicad_sch, divergence_meter_top.kicad_pcb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]
2023-02-17 reviewing top board
    [divergence_meter_logic.kicad_pcb, divergence_meter_top.kicad_pcb, divergence_meter_top.kicad_sch]
2023-02-20 gitignore policies, kicad backups
2023-02-22 testing silkscreen images
    [divergence_meter_logic.kicad_pcb, divergence_meter_top.kicad_pcb]
2023-03-03 reviewed, schemes ok
    [divergence_meter_logic.kicad_pcb, divergence_meter_top.kicad_pcb, divergence_meter_top.kicad_sch]
